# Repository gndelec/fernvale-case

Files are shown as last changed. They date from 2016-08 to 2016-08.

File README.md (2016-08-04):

# Fernvale Open Case Kit

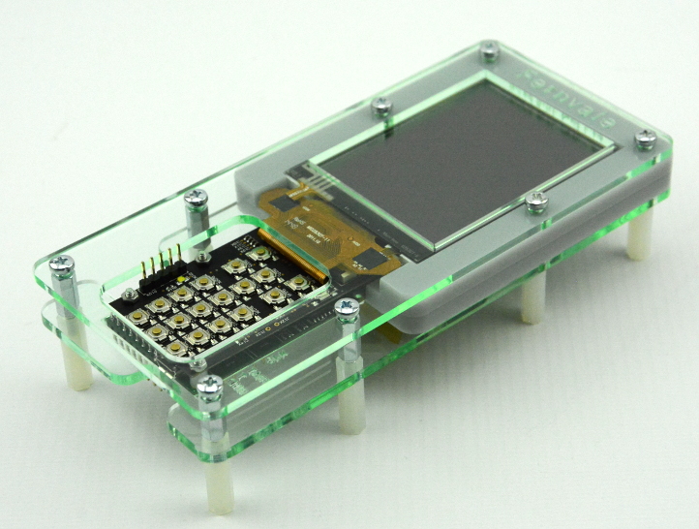
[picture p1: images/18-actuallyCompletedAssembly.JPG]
A Fernvale board fitted in a FDPC-01 case


The FDPC-01 kit is a simple but elegant case based on the "[sick of beige](http://dangerousprototypes.com/docs/Sick_of_Beige_basic_case_v1)" design and is intended to help keep things neat and protected whilst using the Fernvale board. It can be bought from [Ground Electronics](http://groundelectronics.com).

## Repository contents

The case design is provided in the following formats:

* Inkscape SVG (source)
* PDF
* DXF

The top and bottom panels are laser cut from 3mm glass look acrylic.
The middle two layers are cut from 5mm grey acrylic.

## Bill of materials

In addition to the acrylic parts the FDPC-01 kit contains:

| Qty | Item |
| --- | --- |
|  4  | M3 x 8mm steel machine screw |
|  4  | M3 x 20mm steel machine screw |
|  4  | M3 x 10mm steel hex spacer, M-F |
|  8  | M3 steel hex nut |
|  8  | M3 20mm nylon hex spacer, F-F |
|  5  | M2.5 x 12mm steel machine screw |
|  5  | M2.5 steel hex nut |
|  1  | 0.254" pitch pin header x 51 |

Nylon round spacers included with the Fernvale kit are also used:

| Qty | Item |
| --- | --- |
|  3  | M3 x 4mm round nylon spacer |
|  2  | M3 x 3mm round nylon spacer |

## Assembly

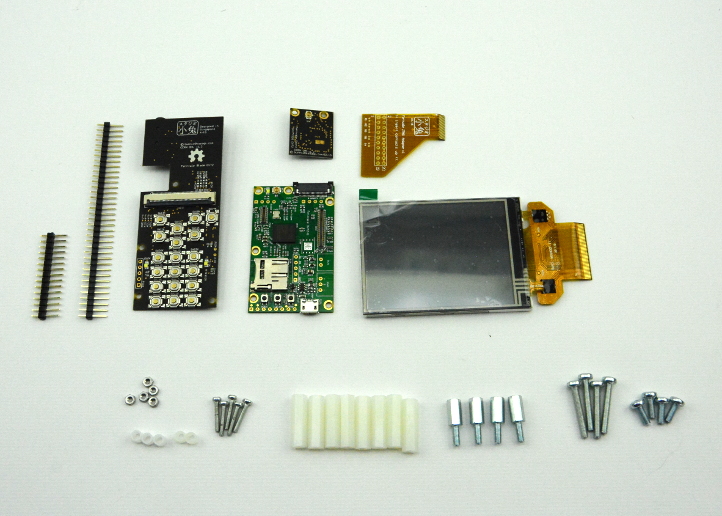
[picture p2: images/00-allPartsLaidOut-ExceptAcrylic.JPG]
Parts laid out


1 Remove the protective plastic from the acrylic panels.

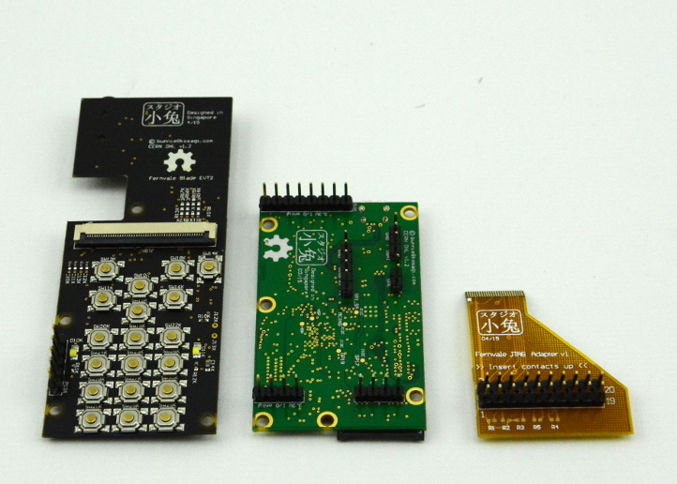
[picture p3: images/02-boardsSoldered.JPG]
Boards with header pins added


2 Snap header pins into suitable lengths, using the Fernvale boards for reference. Take care to solder pins in same orientation as in photo.

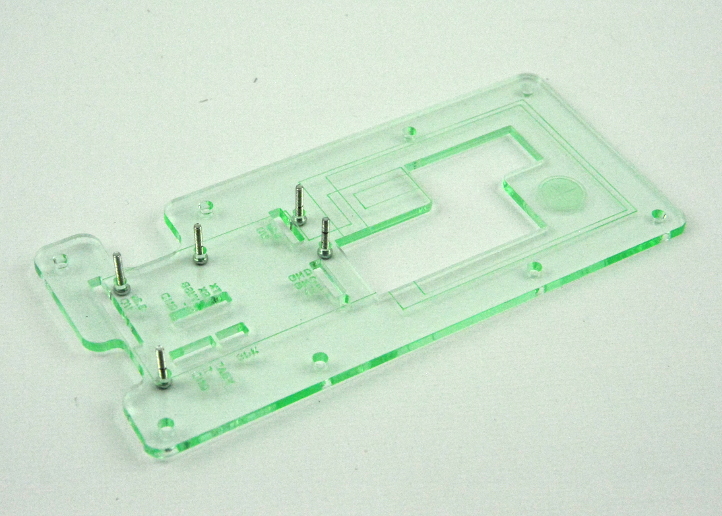
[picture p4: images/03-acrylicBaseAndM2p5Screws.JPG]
Adding M2.5 machine screws


3 Take 5 x M2.5 x 12mm machine screws and insert them into the acrylic base part.

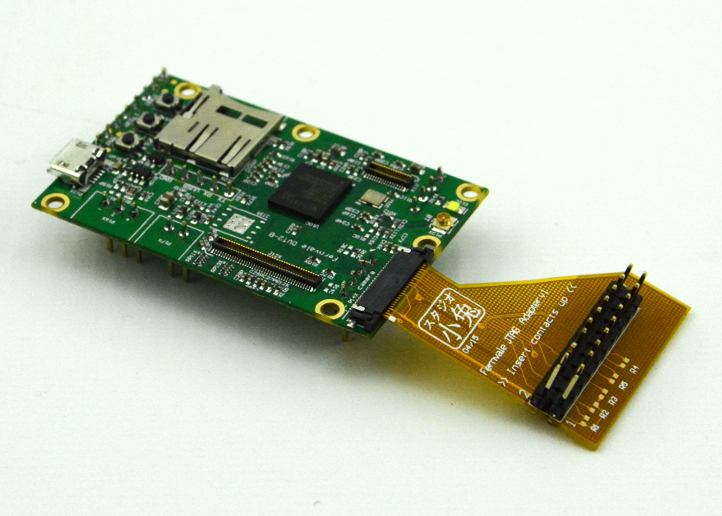
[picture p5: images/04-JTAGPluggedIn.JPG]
Adding JTAG FPCB


4 Connect the optional JTAG FPCB to the main Fernvale board, if you wish to use it.

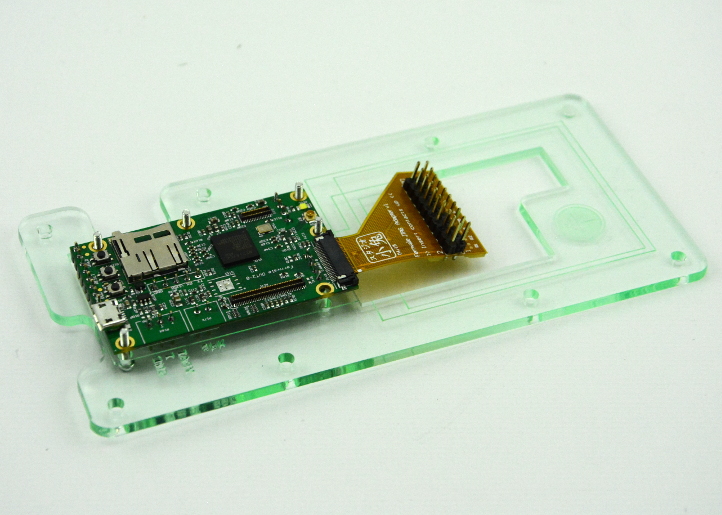
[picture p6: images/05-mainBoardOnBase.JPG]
Adding main board


5 Add the main Fernvale board, taking care that all of the M2.5 machine screws go through the mounting holes correctly.

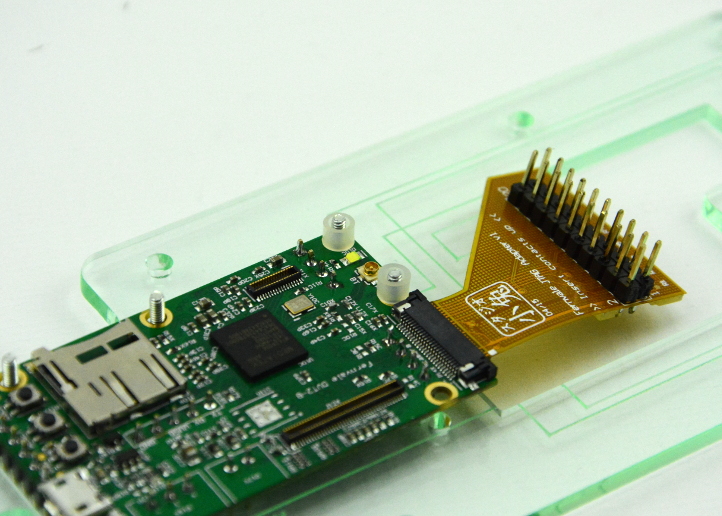
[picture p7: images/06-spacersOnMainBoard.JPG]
Adding supplied short spacers


6 Add the M2.5 x 3mm round spacers, supplied with the Fernvale kit, to the main board, on the two machine screws closest to the JTAG breakout FPCB. Take extra care that you select the correct, shorter spacers here.

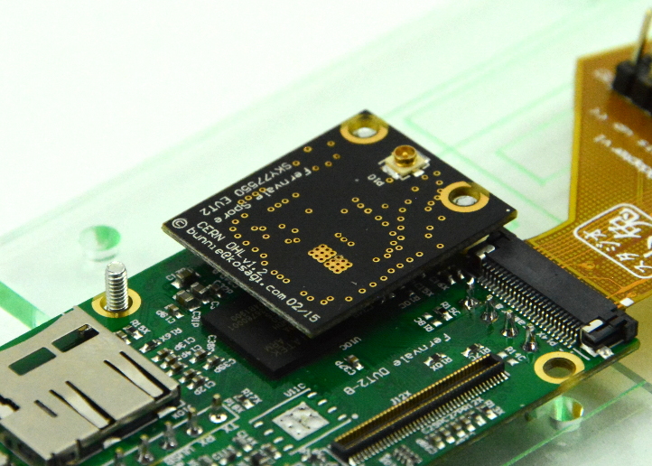
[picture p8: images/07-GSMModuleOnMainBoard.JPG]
Adding GSM board


7 Add the GSM module board, ensuring the connector is lined up before applying suitable pressure to click it into place.

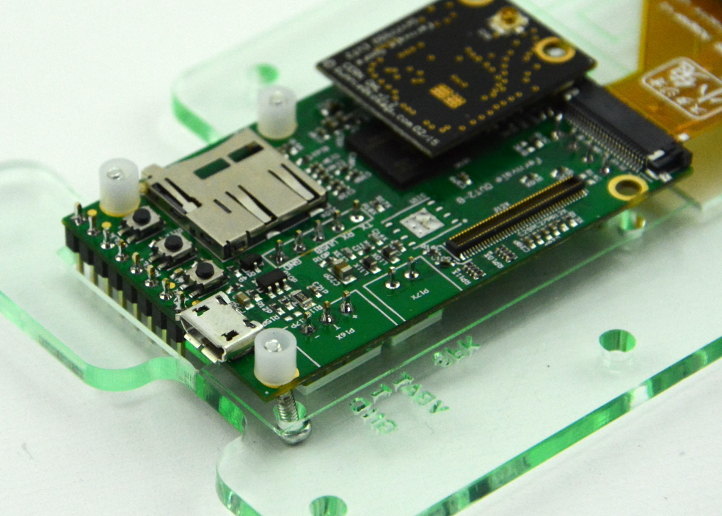
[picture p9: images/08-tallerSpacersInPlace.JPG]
Adding taller supplied spacers


8 Add the M2.5 x 4mm round spacers to the remaining three machine screws.

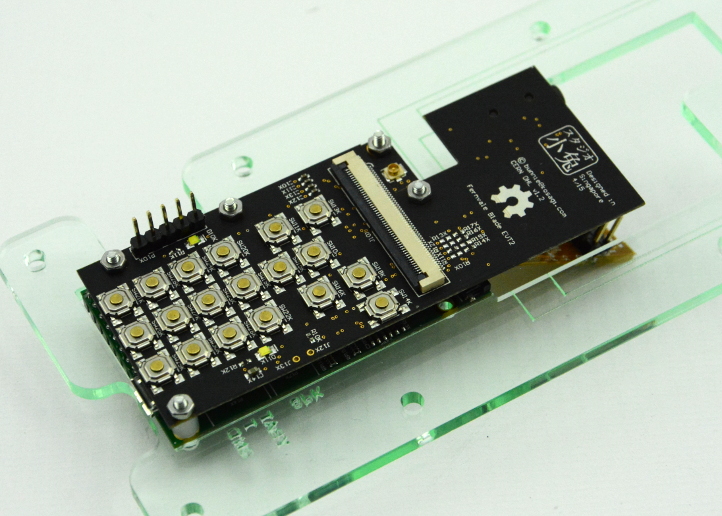
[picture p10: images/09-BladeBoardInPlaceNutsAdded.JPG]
Adding Base board


9 Thread / maneuvre the FPCB JTAG breakout through the bottom acrylic layer. Add the Fernvale Blade board, again taking care to align the high density connector before clicking into place. This step can be fiddly and some machine screws may come free!

10 Add the M2.5 hex nuts to the machine screws and tighten, securing the boards in place.

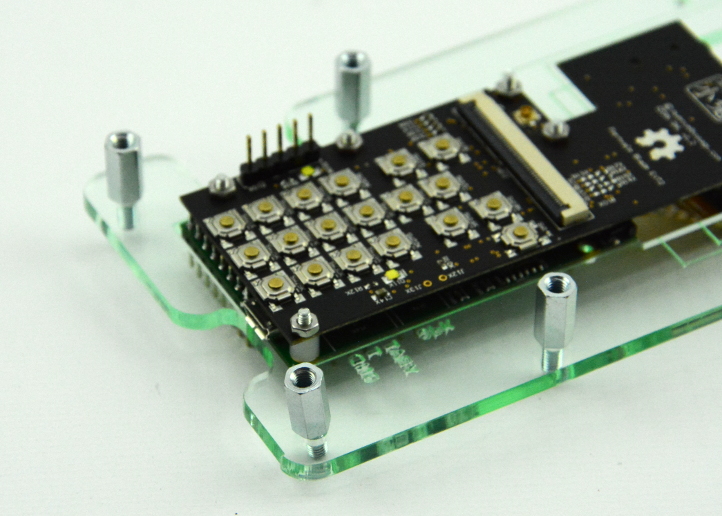
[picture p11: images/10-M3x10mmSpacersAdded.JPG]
Adding steel hex spacers


11 Add the four M3 x 10mm steel hex standoffs to the base acrylic part.

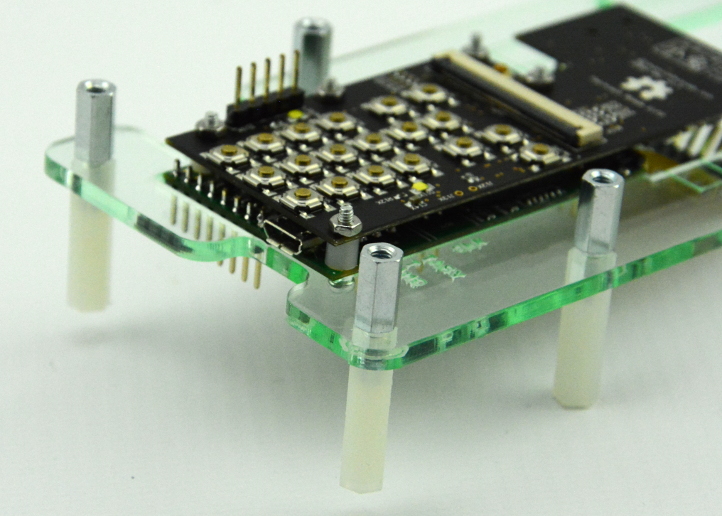
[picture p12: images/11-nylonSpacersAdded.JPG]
Adding nylon hex spacers


12 Add four of the M3 x 20mm nylon hex standoffs to secure the steel standoffs in place.

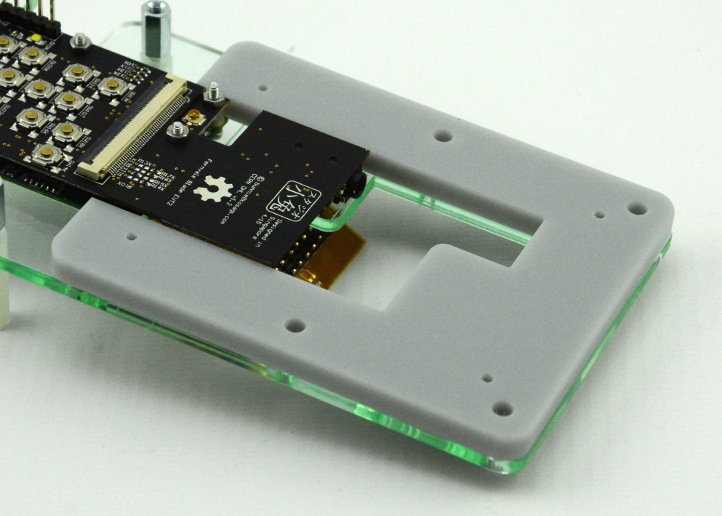
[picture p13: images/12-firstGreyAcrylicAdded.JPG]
Adding first grey acrylic


13 Add the first grey acrylic part, ensuring correct orientation.

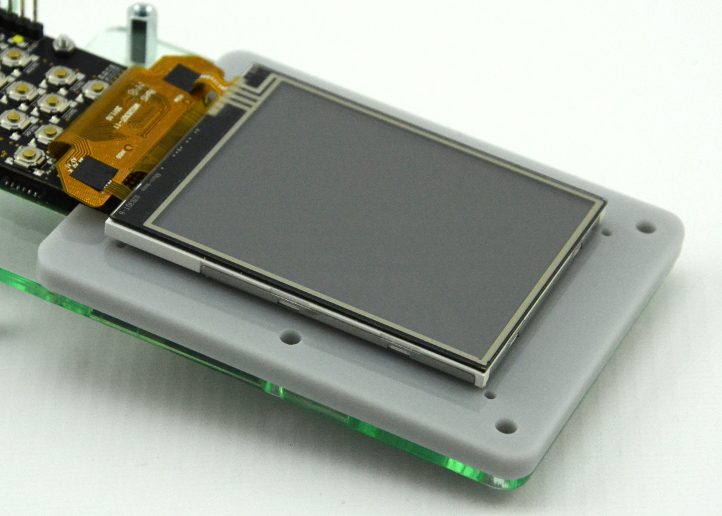
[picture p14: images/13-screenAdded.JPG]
Adding screen


14 Connect the screen and lay it down on the grey acrylic part. Remove the protective screen film if you wish.

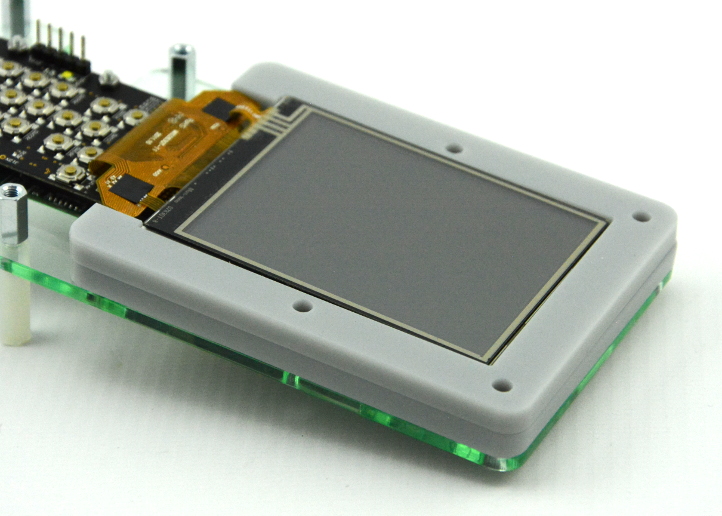
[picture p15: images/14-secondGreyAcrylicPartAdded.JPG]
Adding second grey acrylic


15 Add the second grey acrylic part, taking care when 'farming' it around the screen.

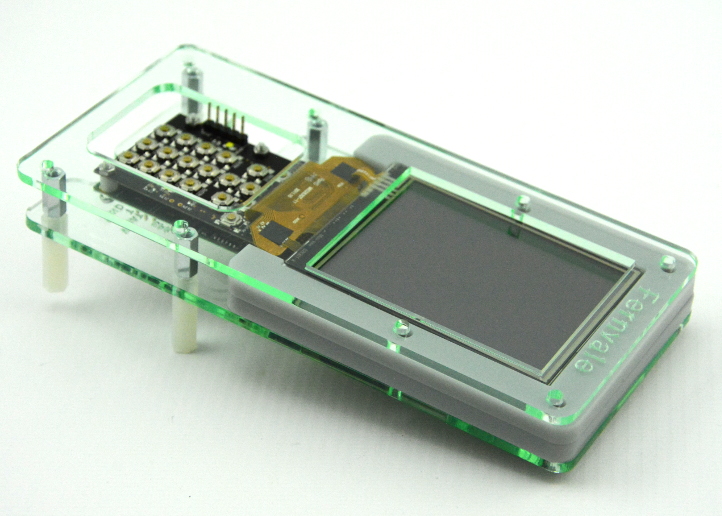
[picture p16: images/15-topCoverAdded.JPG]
Adding top cover acrylic


16 Add the final acrylic top layer.

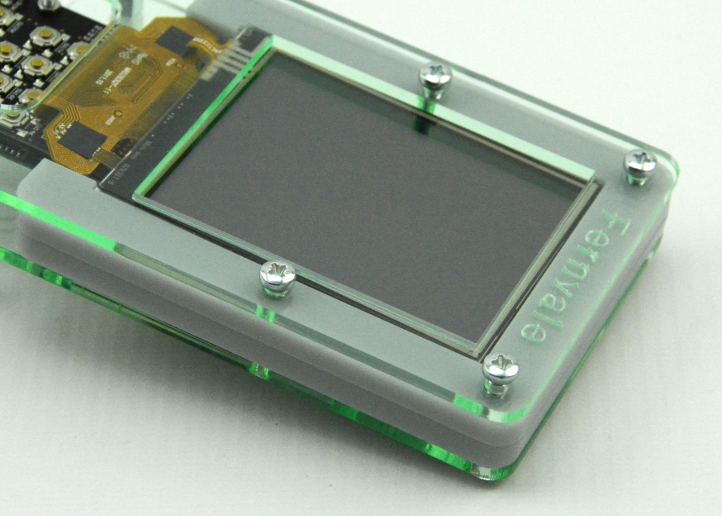
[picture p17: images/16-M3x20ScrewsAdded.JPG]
Adding M3 x 20mm machine screws


17 Add the four M3 x 20mm machine screws through the acrylic layers, from the top.

18 Add the remaining M3 x 20mm nylon hex spacers to the machine screws.

Adding M3 x 20mm machine screws

19 Add the four M3 x 8mm steel machine screws through the acrylic top, tightening them into the M3 x 10mm steel hex standoffs.

## Changelog

| Version | Date | Summary |
|---|---|---|
| 1.0 | 04/08/16 | Initial version. |

## Licence

Fernvale Development Platform Case Kit copyright 2016, [AB Open Ltd](http://abopen.com).

<br />This work is licensed under a <a rel="license" href="http://creativecommons.org/licenses/by/4.0/">Creative Commons Attribution 4.0 International License</a>.

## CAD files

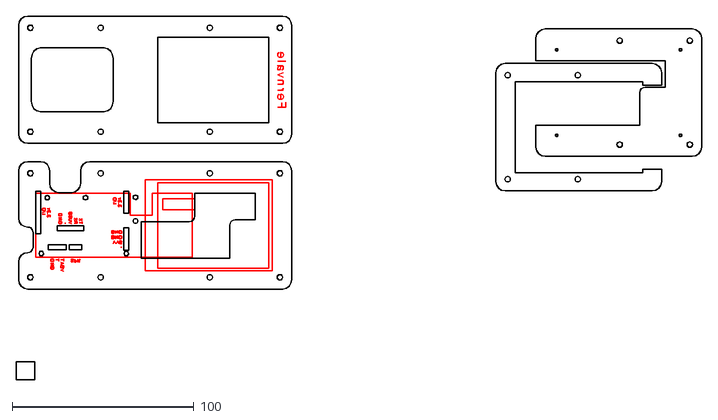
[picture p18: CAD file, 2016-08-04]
FDPC-01.dxf
376.5 x 199.9

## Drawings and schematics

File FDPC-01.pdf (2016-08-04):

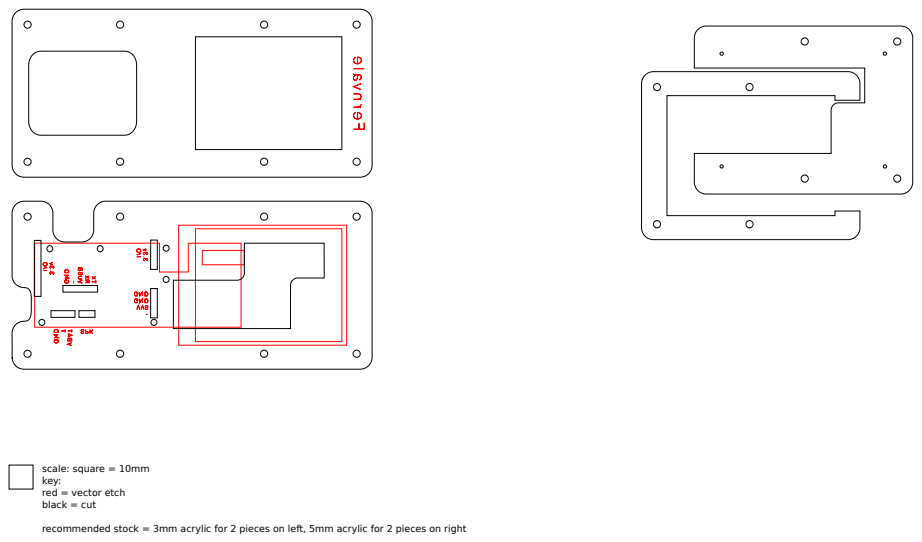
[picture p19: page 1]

scale: square = 10mm
key:
red = vector etch
black = cut

recommended stock = 3mm acrylic for 2 pieces on left, 5mm acrylic for 2 pieces on right

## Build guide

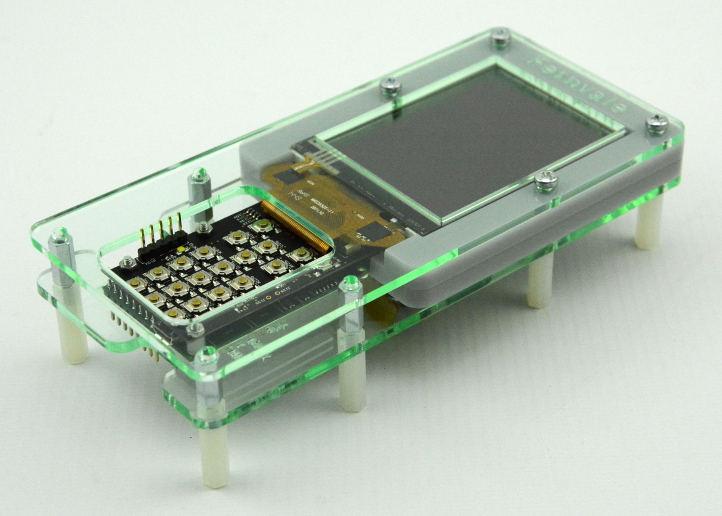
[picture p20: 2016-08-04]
images/17-completedAssembly.JPG

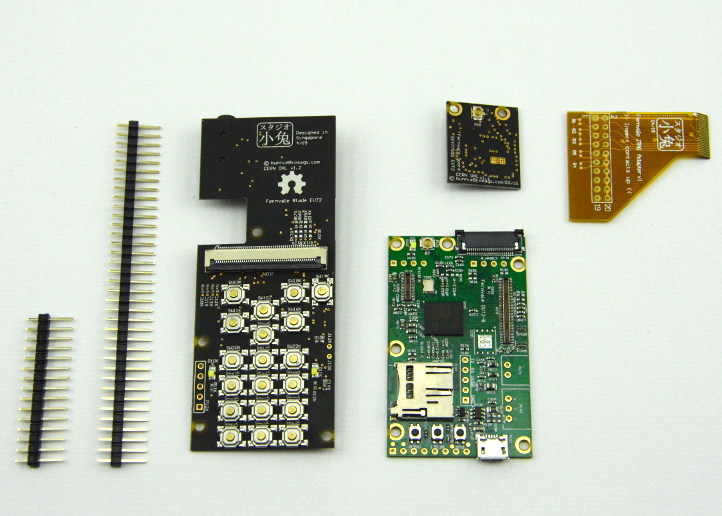
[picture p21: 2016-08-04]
images/01-boardsPreSoldering.JPG
